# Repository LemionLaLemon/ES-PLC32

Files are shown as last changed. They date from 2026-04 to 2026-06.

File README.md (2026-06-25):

# ES-PLC32
The ES-PLC32 is an affordable programmable logic computer with four digital inputs, two analog inputs, and four outputs.
> [!WARNING]
> The ES-PLC32 is not [IEC 61131](https://en.wikipedia.org/wiki/IEC_61131) compliant.

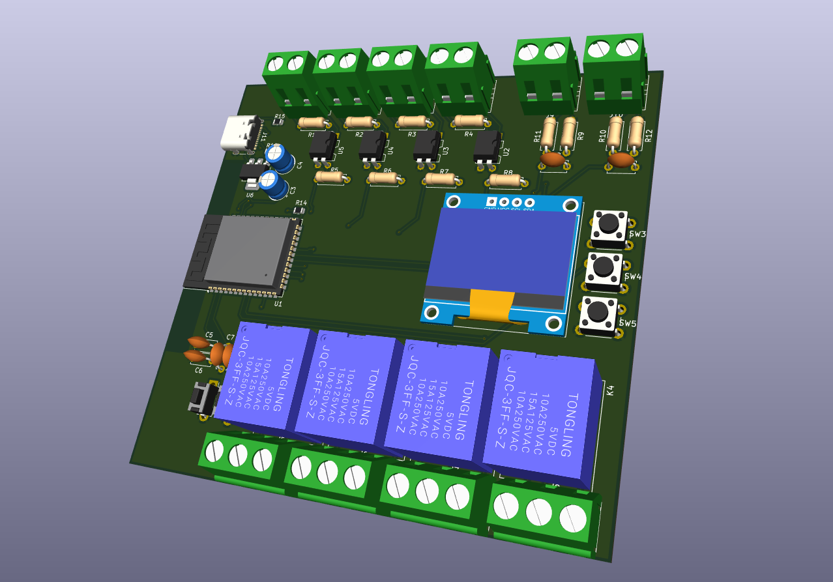
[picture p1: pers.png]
The ES-PLC32


## Digital Inputs
The four digital inputs should be able to handle up to 24v at 20mA but realistically should be used at 3.3v or 5v. The inputs are electrically isolated from the ESP32 via the pc817 optocoupler.

## Analog Inputs
The analog inputs are insanely dangerous to use. It is only able to handle 3.3v-5v and is absolutely not electrically isolated from the ESP32, so any power you push in through that input, will go through two resistors to divide the 5v to 3.3v (or 3.3v to 1v ish) and then directly to the ESP32. (this will be resolved in a later iteration)

## Outputs
The outputs are purely digital and can be used to drive pumps, turn on lights, open motorized valves, and such. There are no analog outputs to keep it affordable.

## Screen and buttons
The 0.96" 128x64 OLED display can be used to change setpoints for anything, view variables live, to restart the program, or start/stop hosting the programming interface, and show the ip for the programming interface.

## Software
The ES-PLC32 uses [OpenPLC](https://autonomylogic.com/) to program in ladder logic (and other languages) and to upload the program to the ES-PLC32. It is recommended to use functional block diagram rather than ladder logic as OpenPLC seems to hate ladder logic a lot.

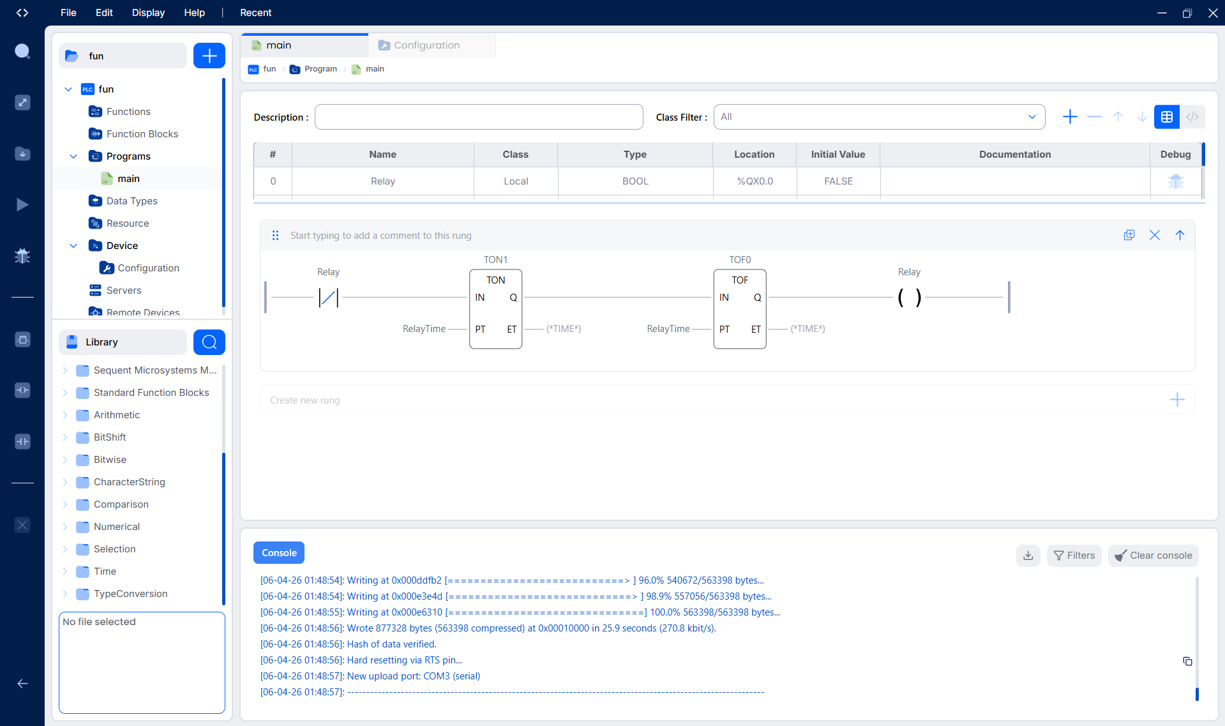
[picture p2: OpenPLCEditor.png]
The OpenPLC Editor


It has inbuilt support for the ESP32-S3 by default and can upload code to it perfectly fine with no issues.

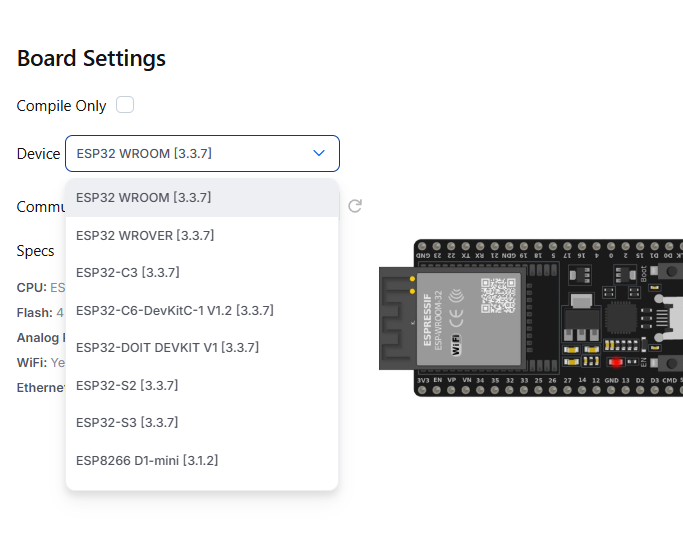
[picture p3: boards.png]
Boards selection in OpenPLC Editor


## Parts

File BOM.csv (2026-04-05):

Name | Qty | Distirbutor | TotalCost | Purpose
100nF THT 2.5mm capacitor | 5 | LCSC | 0.79 | Used to smoothen input analog signals and decoupling for buttons
22uF THT 5mm capacitor | 2 | LCSC | 2.67 | Very much voltage converter and button
10uF THT 5mm capacitor | 1 | LCSC | 1.37 | Very much voltage converter
1uF THT 5mm capacitor | 5 | LCSC | 1.09 | Enable button
Screw Terminal Connector 1x2 | 6 | Shopee | 1.84 | Connectors for digital and analog inputs
Screw Terminal Connector 1x3 | 4 | Shopee | 0.86 | Connectors for relay outputs
USB C connector | 5 | Shopee | 0.4 | Power input and data upload for ESP32
5V Relay | 4 | LCSC | 5.34 | Switch outputs
470R Resistor THT | 4 | LCSC | 0.66 | Current limiting resistors on digital inputs
10k Resistor THT | 6 | LCSC | 3.5 | Prevents noise signals on inputs and voltage divider on analog inputs
20k Resistor THT | 10 | LCSC | 0.33 | Voltage divider on analog inputs
10k Resistor SMD | 100 | LCSC | 0.23 | Boot button
100R Resistor SMD | 100 | LCSC | 0.21 | Boot button
5.1k Resistor SMD | 20 | LCSC | 0.79 | Voltage in
THT Push button switch 6x3.5mm | 2 | Shopee | 1.65 | EN and BOOT buttons
5mm button | 10 | Shopee | 0.77 | UP OK and DN buttons
ESP32-S3-WROOM-1-N8 | 1 | LCSC | 4.79 | Brains for this dumb PLC
Optocoupler | 4 | Shopee | 0.49 | Input isolation
AMS1117-3.3 | 10 | LCSC | 0.4 | 3.3V regulator
1x8 Pin Header Female | 1 | Shopee | 0.31 | For future expansion modules
PCB | 5 | JLCPCB | 2 | circuit board to hold all the components on

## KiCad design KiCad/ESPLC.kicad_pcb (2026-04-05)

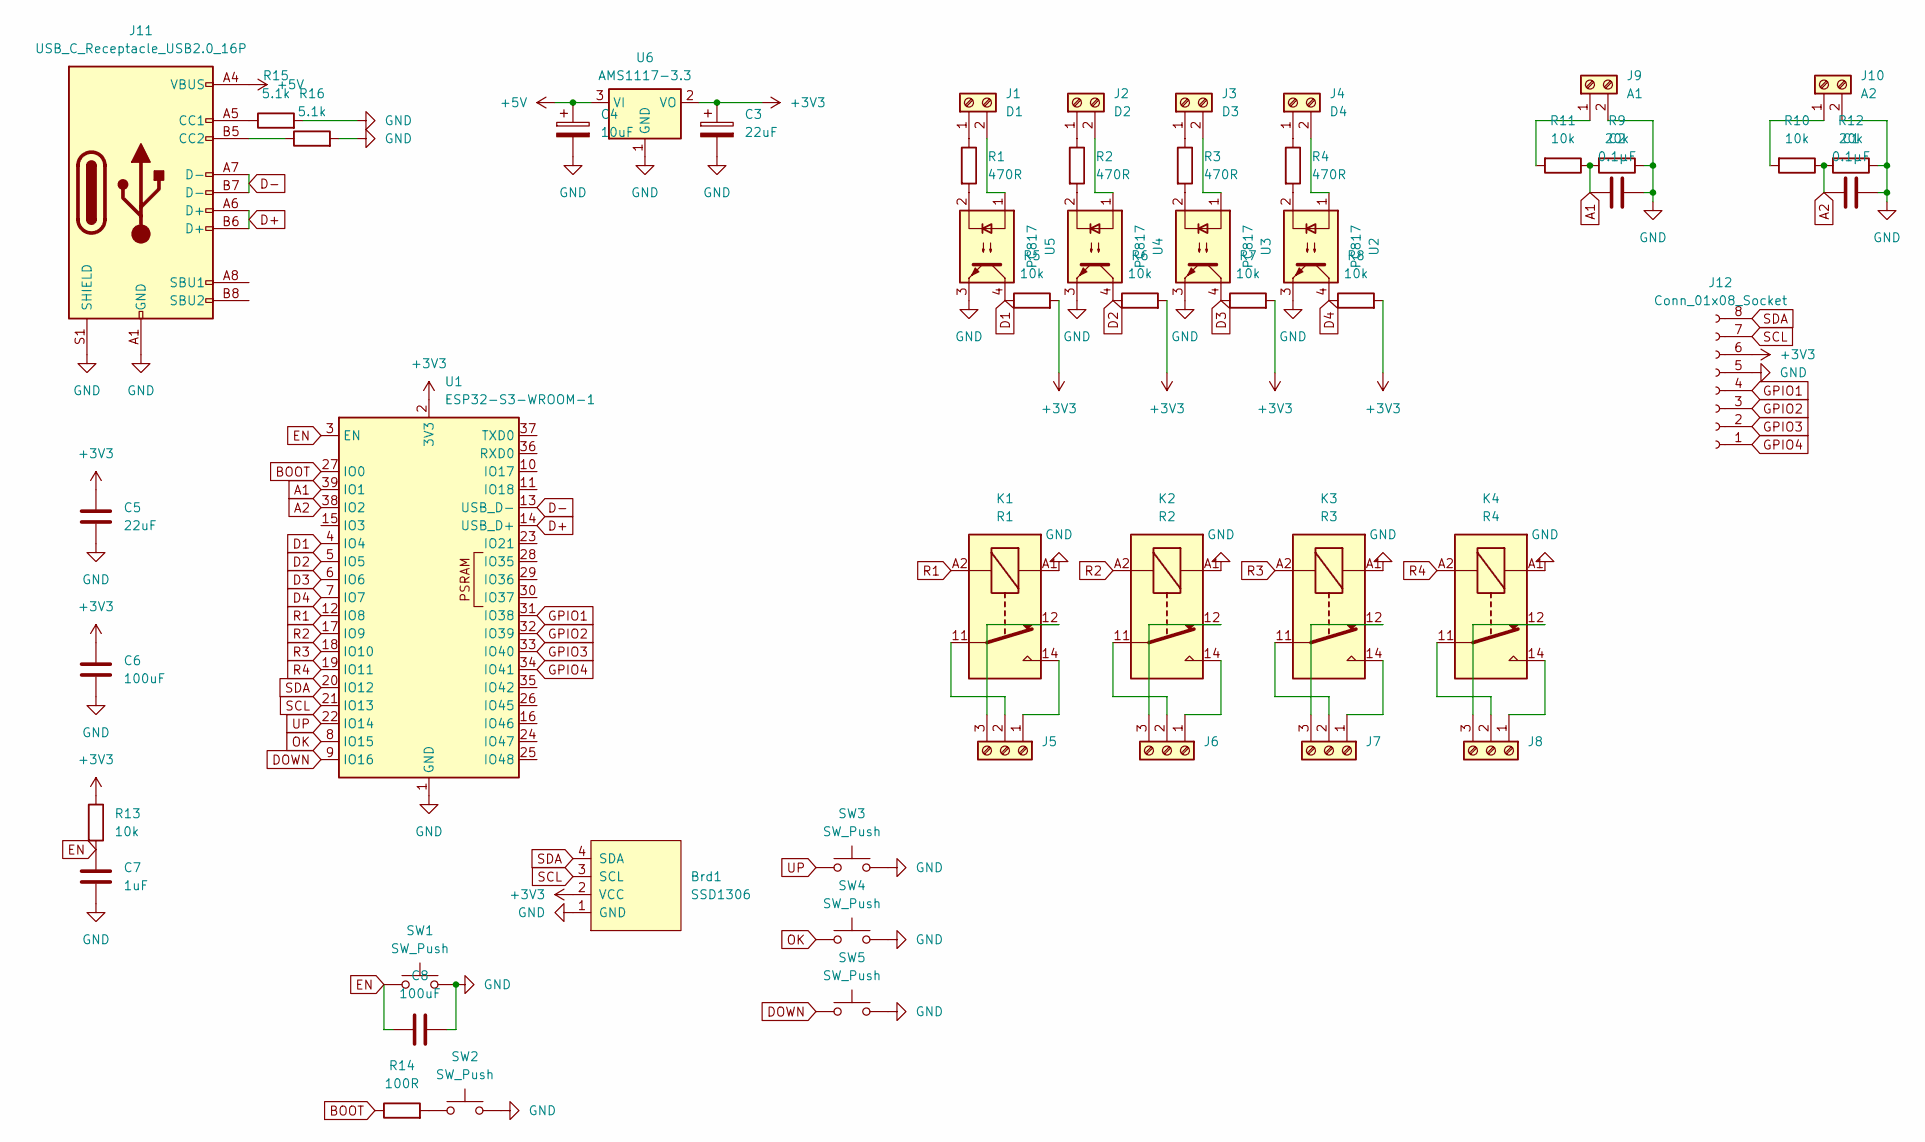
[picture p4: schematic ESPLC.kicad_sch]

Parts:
Brd1: SSD1306; 128x64OLED
C1, C2: 0.1μF; C_Disc_D5.0mm_W2.5mm_P5.00mm
C3: 22uF; CP_Radial_D5.0mm_P2.50mm
C4: 10uF; CP_Radial_D5.0mm_P2.50mm
C5: 22uF; C_Disc_D5.0mm_W2.5mm_P5.00mm
C6, C8: 100uF; C_Disc_D5.0mm_W2.5mm_P5.00mm
C7: 1uF; C_Disc_D5.0mm_W2.5mm_P5.00mm
J1: D1; TerminalBlock-1x2-5.08mm-with3d
J2: D2; TerminalBlock-1x2-5.08mm-with3d
J3: D3; TerminalBlock-1x2-5.08mm-with3d
J4: D4; TerminalBlock-1x2-5.08mm-with3d
J5, J6, J7, J8: Screw_Terminal_01x03; 1x3
J9: A1; TerminalBlock-1x2-5.08mm-with3d
J10: A2; TerminalBlock-1x2-5.08mm-with3d
J11: USB_C_Receptacle_USB2.0_16P; USB_C_Receptacle_GCT_USB4105-xx-A_16P_TopMnt_Horizontal
J12: Conn_01x08_Socket; PinSocket_1x08_P2.00mm_Horizontal
K1: R1; Relay_SPDT_Hongfa_JQC-3FF_0XX-1Z
K2: R2; Relay_SPDT_Hongfa_JQC-3FF_0XX-1Z
K3: R3; Relay_SPDT_Hongfa_JQC-3FF_0XX-1Z
K4: R4; Relay_SPDT_Hongfa_JQC-3FF_0XX-1Z
R1, R2, R3, R4: 470R; R_Axial_DIN0207_L6.3mm_D2.5mm_P7.62mm_Horizontal
R5, R6, R7, R8, R10, R11: 10k; R_Axial_DIN0207_L6.3mm_D2.5mm_P7.62mm_Horizontal
R9, R12: 20k; R_Axial_DIN0207_L6.3mm_D2.5mm_P7.62mm_Horizontal
R13: 10k; R_0805_2012Metric
R14: 100R; R_0805_2012Metric
R15, R16: 5.1k; R_0805_2012Metric
SW1, SW2: SW_Push; SW_PUSH_1P1T_6x3.5mm_H5.0_APEM_MJTP1250
SW3, SW4, SW5: SW_Push; SW_PUSH_6mm_H5mm
U1: ESP32-S3-WROOM-1
U2, U3, U4, U5: PC817; DIP-4_W7.62mm
U6: AMS1117-3.3; SOT-223-3_TabPin2

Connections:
+3V3: Brd1.2 (VCC), C3.1, C5.1, C6.1, J12.6, R5.2, R6.2, R7.2, R8.2, R13.1, U1.2 (3V3), U6.2 (VO)
+5V: C4.1, J11.A4 (VBUS), J11.A9 (VBUS), J11.B4 (VBUS), J11.B9 (VBUS), U6.3 (VI)
A1: C2.1, R9.2, R11.1, U1.39 (IO1)
A2: C1.1, R10.1, R12.2, U1.38 (IO2)
BOOT: R14.1, U1.27 (IO0)
D1: R5.1, U1.4 (IO4), U5.4
D2: R6.1, U1.5 (IO5), U4.4
D3: R7.1, U1.6 (IO6), U3.4
D4: R8.1, U1.7 (IO7), U2.4
D+: J11.A6 (D+), J11.B6 (D+), U1.14 (USB_D+)
D-: J11.A7 (D-), J11.B7 (D-), U1.13 (USB_D-)
DOWN: SW5.1, U1.9 (IO16); also elsewhere on the board
EN: C7.1, C8.1, R13.2, SW1.1, U1.3 (EN)
GND: Brd1.1 (GND), C1.2, C2.2, C3.2, C4.2, C5.2, C6.2, C7.2, C8.2, J9.2, J10.2, J11.A1 (GND), J11.A12 (GND), J11.B1 (GND), J11.B12 (GND), J11.S1 (SHIELD), J12.5, K1.A1, K2.A1, K3.A1, K4.A1, R9.1, R12.1, R15.2, R16.2, SW1.2, SW2.2, SW3.2, SW4.2, SW5.2, U1.1 (GND), U1.40 (GND), U1.41 (GND), U2.3, U3.3, U4.3, U5.3, U6.1 (GND); also elsewhere on the board
GPIO1: J12.4, U1.31 (IO38)
GPIO2: J12.3, U1.32 (IO39)
GPIO3: J12.2, U1.33 (IO40)
GPIO4: J12.1, U1.34 (IO41)
unnamed: J1.1, R1.1
unnamed: J1.2, U5.1
unnamed: J2.1, R2.1
unnamed: J2.2, U4.1
unnamed: J3.1, R3.1
unnamed: J3.2, U3.1
unnamed: J4.1, R4.1
unnamed: J4.2, U2.1
unnamed: J5.1, K1.14
unnamed: J5.2, K1.11
unnamed: J5.3, K1.12
unnamed: J6.1, K2.14
unnamed: J6.2, K2.11
unnamed: J6.3, K2.12
unnamed: J7.1, K3.14
unnamed: J7.2, K3.11
unnamed: J7.3, K3.12
unnamed: J8.1, K4.14
unnamed: J8.2, K4.11
unnamed: J8.3, K4.12
unnamed: J9.1, R11.2
unnamed: J10.1, R10.2
unnamed: J11.A5 (CC1), R15.1
unnamed: J11.B5 (CC2), R16.1
unnamed: R1.2, U5.2
unnamed: R2.2, U4.2
unnamed: R3.2, U3.2
unnamed: R4.2, U2.2
unnamed: R14.2, SW2.1
OK: SW4.1, U1.8 (IO15); also elsewhere on the board
R1: K1.A2, U1.12 (IO8)
R2: K2.A2, U1.17 (IO9)
R3: K3.A2, U1.18 (IO10)
R4: K4.A2, U1.19 (IO11)
SCL: Brd1.3 (SCL), J12.7, U1.21 (IO13)
SDA: Brd1.4 (SDA), J12.8, U1.20 (IO12)
UP: SW3.1, U1.22 (IO14); also elsewhere on the board

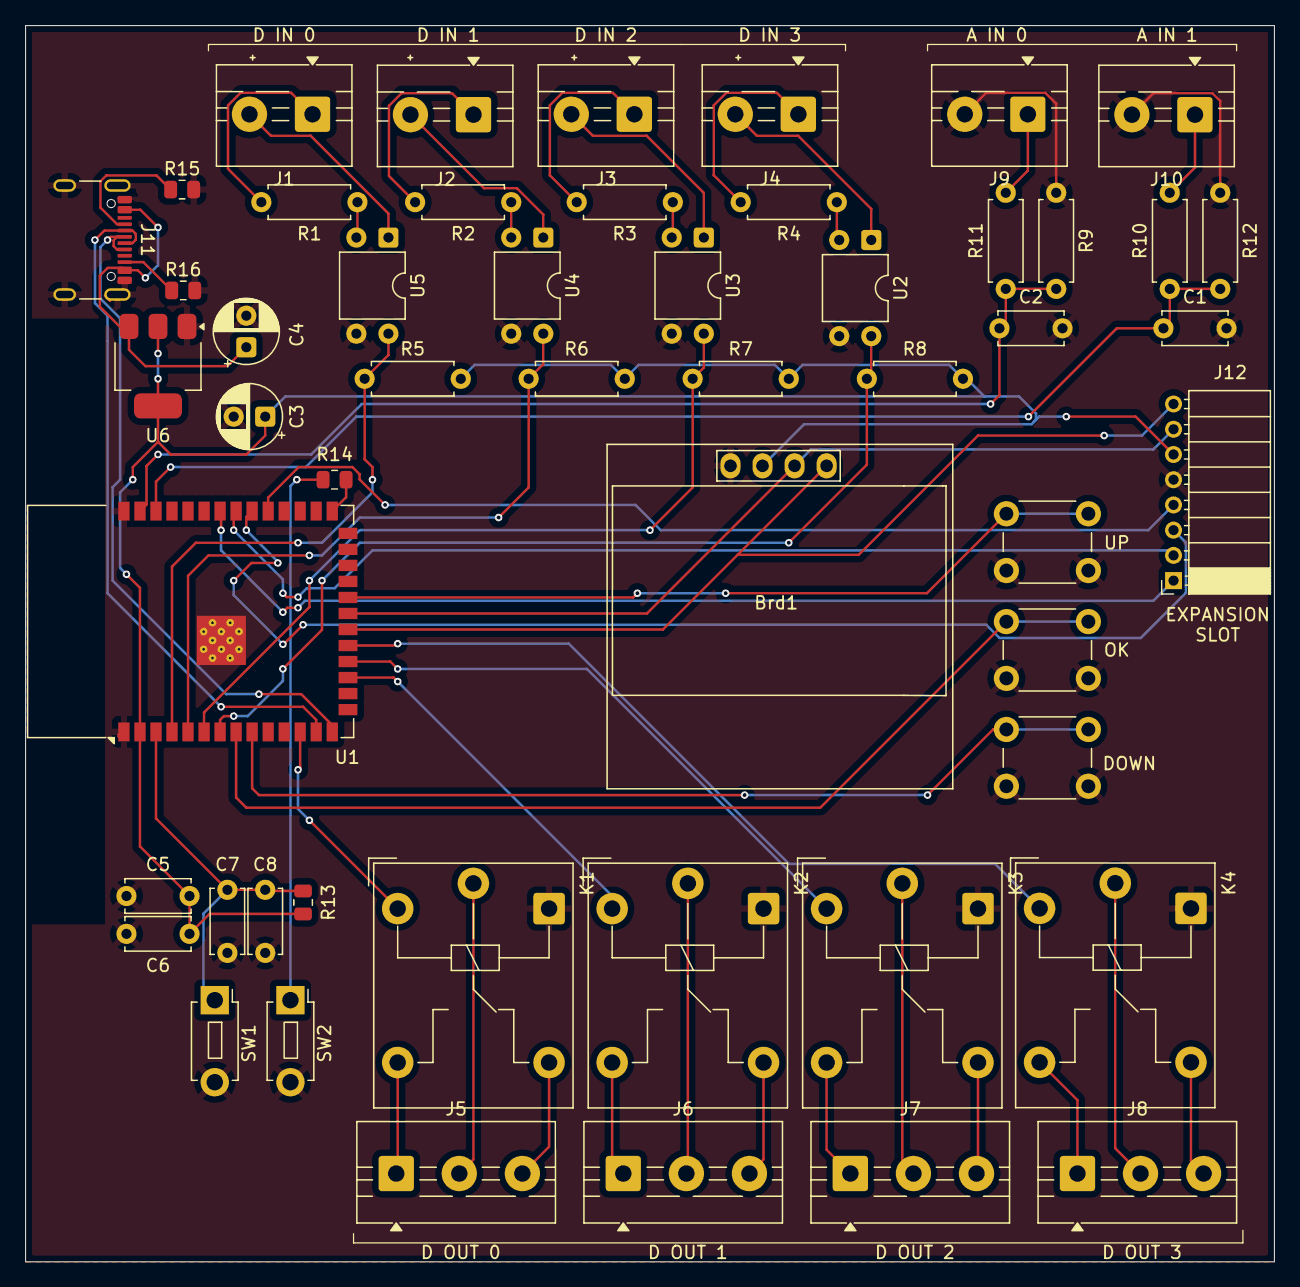
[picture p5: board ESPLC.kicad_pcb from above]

Board: 2 copper layers, 99.0 x 98.0 mm, 52 parts (0 on the bottom side), 55 nets.

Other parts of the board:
DOWN: SW_Push; SW_PUSH_6mm_H5mm
OK: SW_Push; SW_PUSH_6mm_H5mm
UP: SW_Push; SW_PUSH_6mm_H5mm

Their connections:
DOWN: DOWN.1; also elsewhere on the board
GND: DOWN.2, OK.2, UP.2; also elsewhere on the board
OK: OK.1; also elsewhere on the board
UP: UP.1; also elsewhere on the board

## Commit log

2026-04-05 Added BOM
    [BOM.csv]
2026-04-05 Added Software section to README, updated Gerber
    [ESPLC.kicad_pcb, ESPLC.kicad_sch]
